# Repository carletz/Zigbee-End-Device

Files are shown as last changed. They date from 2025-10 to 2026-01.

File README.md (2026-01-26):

# Zigbee End Device V2 (Contact Sensor)

This project is a **Zigbee End Device** designed to operate as a **battery-powered contact sensor** (for doors, windows, or similar applications).  
It is based on the **Texas Instruments CC2530** Zigbee SoC and can be flashed with the **PTVO firmware** to provide full Zigbee functionality.

The aim of this project is to replicate the door/window contact and try to do it as small as possible. The first attempt was made with 0402 components, easy and beautiful to design but extremely hard in the real life to solder. This version is based on 0603 pieces which are "more easy" to prepare by hand.
I've do my best! 🤣

Okay, okay... I've discovered hot water...  these are sensors that can be easily purchased off the shelf without too many problems, I know. The purpose of my work was simply to try to understand how they work and, consequently, their potential, starting with the oldest and most established chip on the market. It's not a major innovation, but it certainly helps us understand the possibilities ahead.

📂 [--&gt; My OshwLab repository of the project](https://oshwlab.com/carletz.slug/zigbee-end-device-v21) 

---
## 🎥 Construction Video

Watch the video (https://youtu.be/N2DPDZoxfj0) 
---

## 🧩 Features

- Zigbee 1.2 compatible (using [PTVO firmware](https://ptvo.info/))
- Based on **CC2530F256** microcontroller  
- Powered by a **CR2032 coin cell**
- Integrated **reed switch** for contact detection  
- **LED indicator** for status or pairing feedback  
- **Reset button** for firmware or network reset  
- Compact design suitable for enclosure integration  

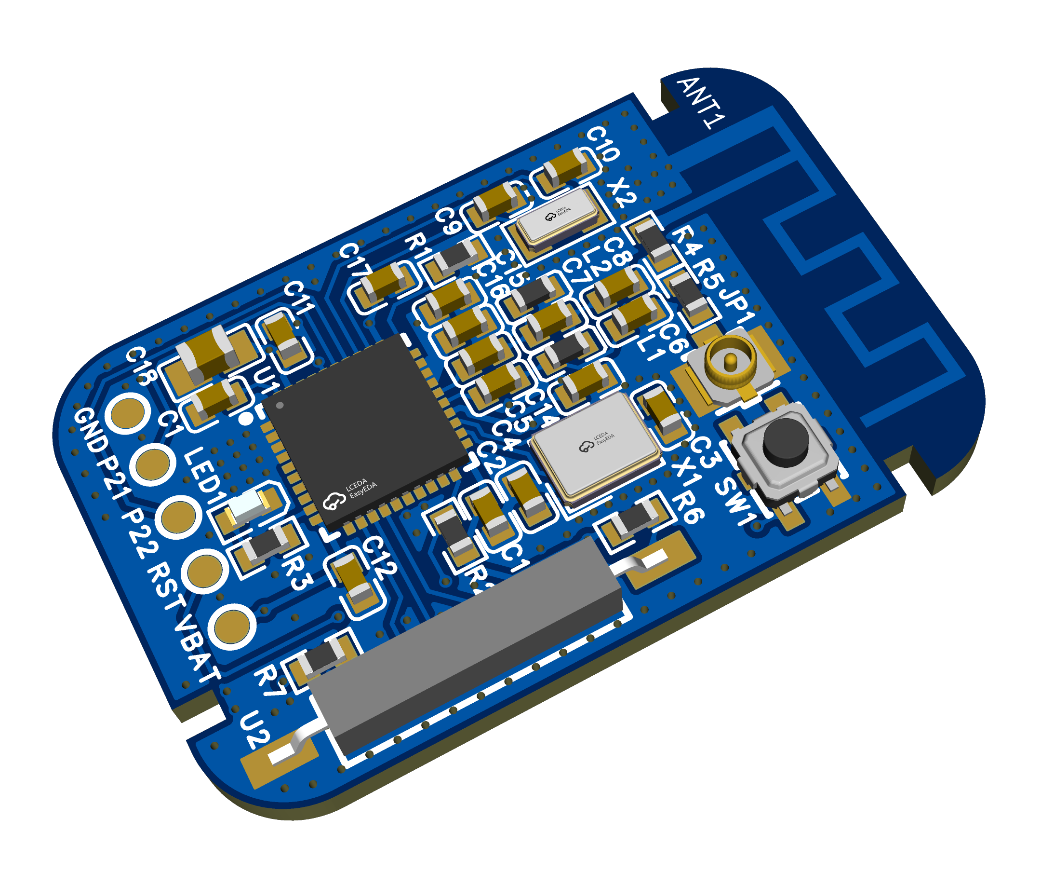
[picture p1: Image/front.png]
Render 1


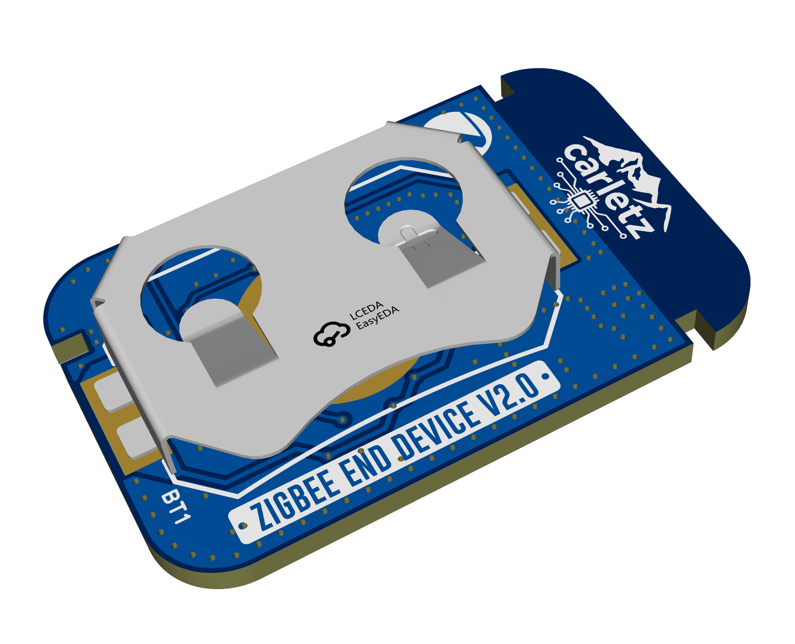
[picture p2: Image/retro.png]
Render 2


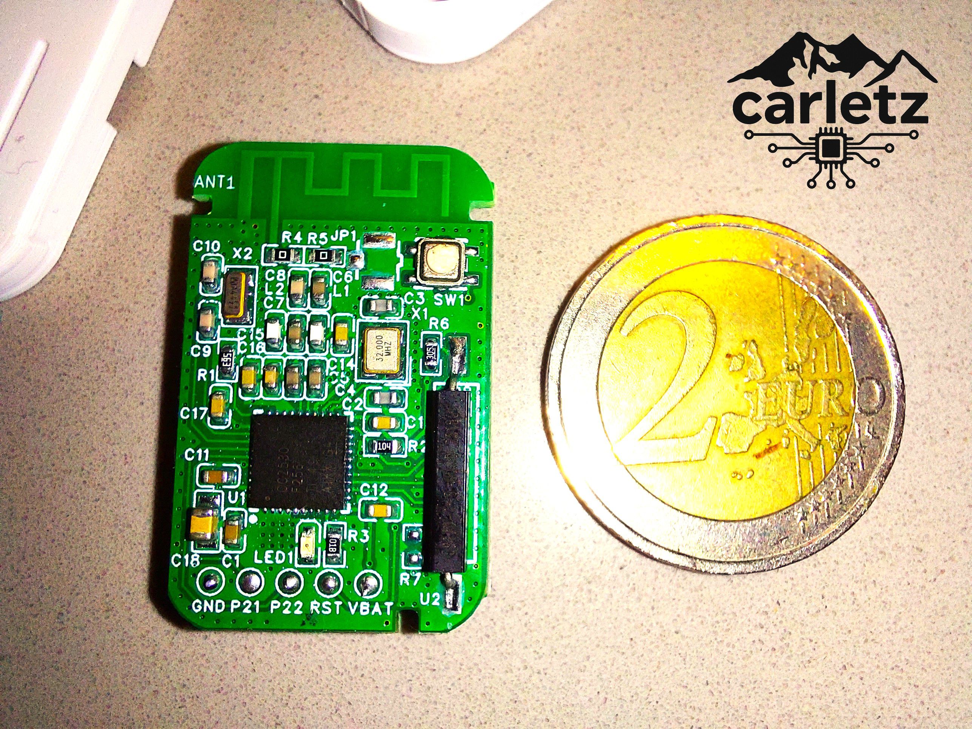
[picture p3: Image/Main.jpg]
Render 3

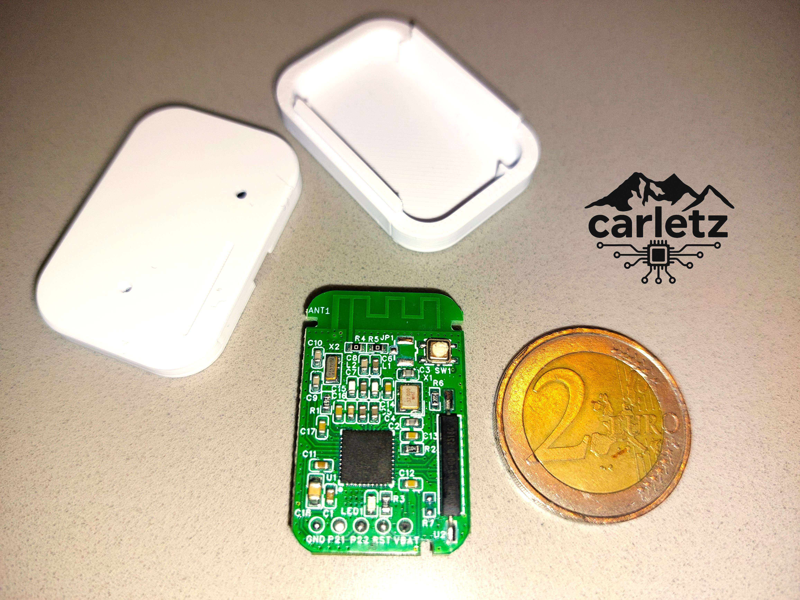
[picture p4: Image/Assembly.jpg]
Render 4

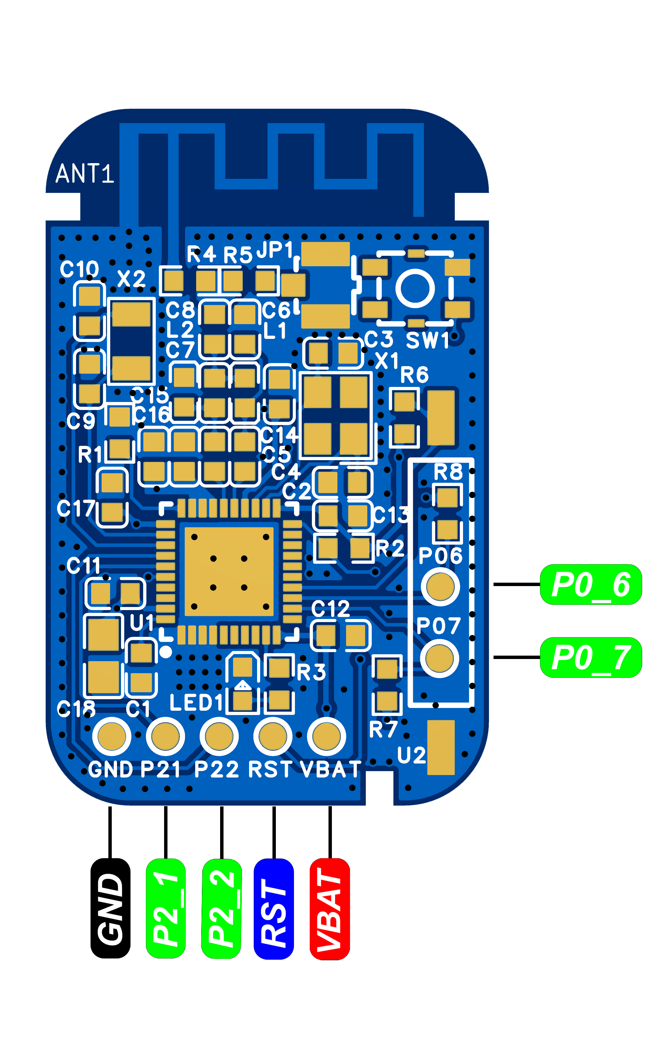
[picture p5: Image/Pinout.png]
Render 5


---
## ⚠️ Notes
- Pogo pins on the left are only for programming.
- I've added also the base for an external antenna but I didn't use it.
---

## 🛠️ Tools &amp; Compatibility

- Designed in **EasyEDA**
- Compatible with **Zigbee2MQTT**, **Home Assistant**, **OpenHAB**, and other automation platforms
- Zigbee module (CC2530) flashable via programmer and **TI Flash Programmer** 

## ⚙️ Firmware

The hardware is compatible with the **PTVO Zigbee firmware** generator:  
👉 [https://ptvo.info](https://ptvo.info)

You can configure the firmware as an **End Device (battery-powered)** and assign the reed contact input to the relative GPIO.

Once the configuration is ready, download the `.hex` file generated by the PTVO tool and flash it to the CC2530 chip.

---

## 🔋Battery

I wanted to try battery power for the first time on a simple project. With the configuration I used, the precautions taken to connect the sensor and power capacitors, and the firmware configuration, the sleep power consumption is approximately 3-4 µA, which guarantees significant battery life.

---

## 🔧 Flashing Instructions

To upload the firmware to the CC2530, follow these steps:

1. **Required tools:**
   - A **CC Debugger** or compatible programmer (I've used the cheaper SmartRF04EB)
   - The **SmartRF Flash Programmer** or **TI Flash Programmer** software
   - The `.hex` file generated by PTVO

2. **Connections:**

   | CC2530 Pin | CC Debugger Pin |
   |-------------|-----------------|
   | `P2_2` (Debug Data) | `DD` |
   | `P2_1` (Debug Clock) | `DC` |
   | `GND` | `GND` |
   | `VCC` | `VCC` (3.3 V) |
   | `RESET_N` | `RESET` |

Others test point applied are for eventually future implementations whit an optiona pull-up resistor.

3. **Flashing procedure:**
   - Connect the programmer board to the Zigbee End Device board.
   - Verify that the programmer board LED turns red (indicating correct connection).
   - Open **SmartRF Flash Programmer**.
   - Select the connected device (**CC2530**).
   - Choose your `.hex` file.
   - Click **Program** and wait for the operation to complete.

4. **After flashing:**
   - Disconnect the programmer.
   - Power the device from the CR2032 battery.
   - The LED should blink once at startup, and the device will join the Zigbee network when powered.

---

## 💡 Credits

This project is inspired by and based on designs shared by **[DIY&amp;Zi](https://oshwlab.com/novgorod73/works)** on [OSHWHub / OSHWLab](https://oshwlab.com).  
Special thanks to **PTVO** for providing a lot of informations for the tune of this board and flexible **Zigbee firmware generator**.

---

## 📬 Author

**carletz**  
Created: January 2026
This project is open hardware, released under the MIT License.

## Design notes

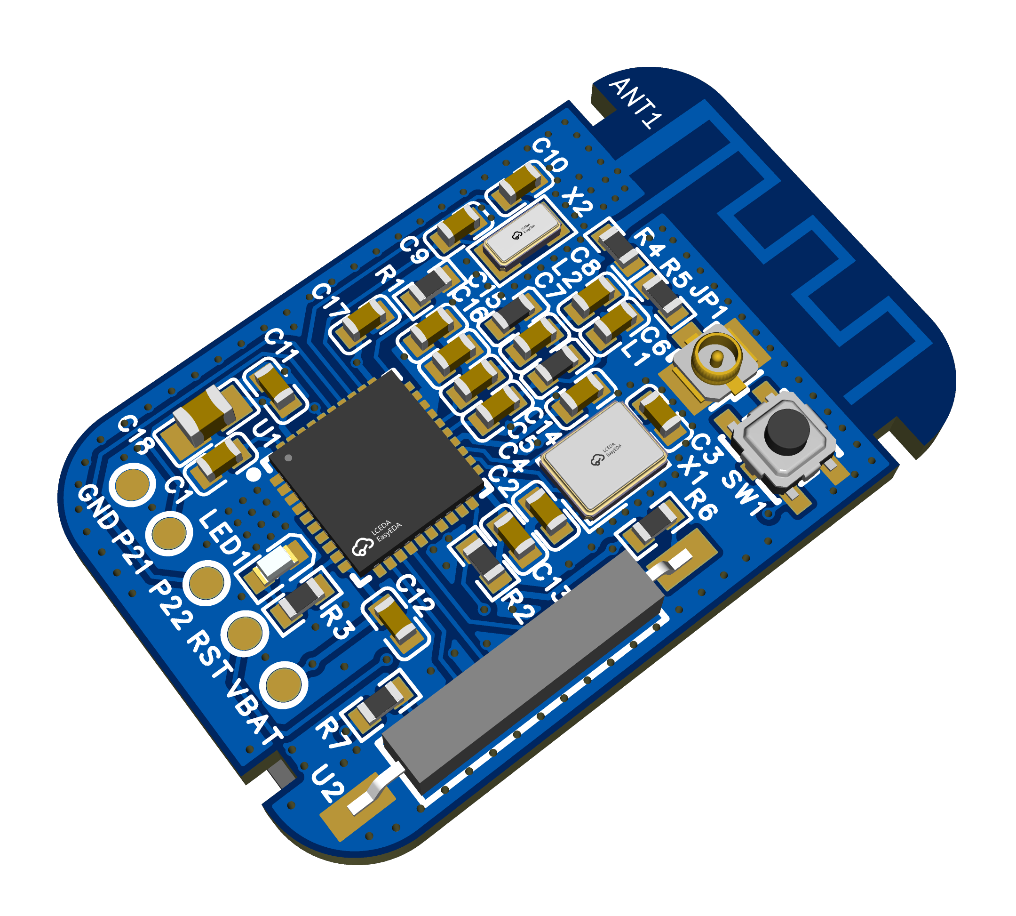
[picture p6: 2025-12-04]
Image/top.png

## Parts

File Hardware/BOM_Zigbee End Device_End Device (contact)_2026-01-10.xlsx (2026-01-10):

No. | Quantity | Comment | Designator | Footprint | Value | Manufacturer Part | Manufacturer | Supplier Part | Supplier | LCSC Stock | LCSC Price | Primary Category | Secondary Category | Pin Count | JLCPCB Stock | JLCPCB Price | 3D Model Title | Device | Name | Unique ID | Convert to PCB | Add into BOM | Symbol
1 | 1 | MY-2032-12 | BT1 | BAT-SMD_MY-2032-12 |  | MY-2032-12 | MYOUNG(美阳) | C964833 | LCSC |  |  | Connectors | Button And Strip Battery Connector | 2 | 18862 | 0.0198 | BAT-SMD_MY-2032-12 | MY-2032-12 | MY-2032-12 | gge17 | yes | yes | MY-2032-12
2 | 2 | 1uF | C1,C11 | C0603 | 1uF | CL10A105KA8NNNC | SAMSUNG(三星) | C5673 | LCSC |  |  | Capacitors | Multilayer Ceramic Capacitors MLCC - SMD/SMT | 2 | 1186170 | 0.0007 | C0603_L1.6-W0.8-H0.8 | CL10A105KA8NNNC | 1uF | gge37,gge38 | yes | yes | CL10A105KA8NNNC
3 | 2 | 27pF | C2,C3 | C0603 | 27pF | CGA0603C0G270J500JT | HRE(芯声) | C42371680 | LCSC |  |  | Capacitors | Multilayer Ceramic Capacitors MLCC - SMD/SMT | 2 | 0 |  | C0603_L1.6-W0.8-H0.8 | CGA0603C0G270J500JT | 27pF | gge50,gge51 | yes | yes | CGA0603C0G270J500JT
4 | 2 | 18pF | C4,C5 | C0603 | 18pF | FCC0603N180J500CT | FOJAN(富捷) | C5137620 | LCSC |  |  | Capacitors | Multilayer Ceramic Capacitors MLCC - SMD/SMT | 2 | 412623 | 0.0004 | C0603_L1.6-W0.8-H0.8 | FCC0603N180J500CT | 18pF | gge56,gge57 | yes | yes | FCC0603N180J500CT
5 | 2 | 1pF | C6,C7 | C0603 | 1pF | FCC0603N1R0C500CT | FOJAN(富捷) | C5137611 | LCSC |  |  | Capacitors | Multilayer Ceramic Capacitors MLCC - SMD/SMT | 2 | 154670 | 0.0004 | C0603_L1.6-W0.8-H0.8 | FCC0603N1R0C500CT | 1pF | gge52,gge53 | yes | yes | FCC0603N1R0C500CT
6 | 1 | 2.2pF | C8 | C0603 | 2.2pF | 0603CG2R2C500NT | FH(风华) | C1651 | LCSC |  |  | Capacitors | Multilayer Ceramic Capacitors MLCC - SMD/SMT | 2 | 137377 | 0.0005 | C0603_L1.6-W0.8-H0.8 | 0603CG2R2C500NT | 2.2pF | gge58 | yes | yes | 0603CG2R2C500NT
7 | 2 | 15pF | C9,C10 | C0603 | 15pF | 0603CG150J500NT | FH(风华) | C91703 | LCSC |  |  | Capacitors | Multilayer Ceramic Capacitors MLCC - SMD/SMT | 2 | 114833 | 0.0005 | C0603_L1.6-W0.8-H0.8 | 0603CG150J500NT | 15pF | gge39,gge40 | yes | yes | 0603CG150J500NT
8 | 5 | 100nF | C12,C13,C14,C15,C17 | C0603 | 100nF | CL10B104KO8NNNC | SAMSUNG(三星) | C66501 | LCSC |  |  | Capacitors | Multilayer Ceramic Capacitors MLCC - SMD/SMT | 2 | 568617 | 0.0005 | C0603_L1.6-W0.8-H0.8 | CL10B104KO8NNNC | 100nF | gge41,gge42,gge43,gge44,gge45 | yes | yes | CL10B104KO8NNNC
9 | 1 | 220pF | C16 | C0603 | 220pF | CC0603KRX7R9BB221 | YAGEO(国巨) | C107081 | LCSC |  |  | Capacitors | Multilayer Ceramic Capacitors MLCC - SMD/SMT | 2 | 580953 | 0.0005 | C0603_L1.6-W0.8-H0.8 | CC0603KRX7R9BB221 | 220pF | gge59 | yes | yes | CC0603KRX7R9BB221
10 | 1 | 100uF | C18 | C0805 | 100uF | GRM21BR60J107ME15L | muRata(村田) | C141660 | LCSC |  |  | Capacitors | Multilayer Ceramic Capacitors MLCC - SMD/SMT | 2 | 114779 | 0.0359 | C0805_L2.0-W1.3-H1.3 | GRM21BR60J107ME15L | 100uF | gge36 | yes | yes | GRM21BR60J107ME15L
11 | 7 | 3V3 | GND,P06,P07,P21,P22,RST,VBAT | TESTPOINT-TH_BD3.2_1 |  | 3V3 |  | C9900007422 | LCSC |  |  |  |  | 1 | 0 | 0.0002 |  | TPoint2 | 3V3 | gge122_2,gge122_3,gge122_4,gge122_5,gge122_6,gge122_7,gge122_8 | yes | yes | TPoint2
12 | 1 | 6GHz | JP1 | RF-SMD_FRF05002-JSS103M | 6GHz | U.FL-R-SMT-1(80) | HRS(广濑) | C88374 | LCSC |  |  | Connectors | Coaxial Connectors (RF) | 3 | 69527 | 0.0179 | RF-SMD_FRF05002-JSS103M | U.FL-R-SMT-1(80)_C88374 | 6GHz | gge34 | yes | yes | U.FL-R-SMT-1(80)
13 | 2 | 2nH | L1,L2 | L0603 | 2nH | VHF160808H2N0ST | FH(风华) | C395081 | LCSC |  |  | Inductors, Coils, Chokes | Inductors (SMD) | 2 | 13488 | 0.0012 | L0603_L1.6-W0.8-H0.5_BEAD | VHF160808H2N0ST | 2nH | gge54,gge55 | yes | yes | VHF160808H2N0ST
14 | 1 | MHT192CRCT | LED1 | LED0603-RD |  | MHT192CRCT | MEIHUA(美华) | C389517 | LCSC |  |  | Optoelectronics | LED Indication - Discrete | 2 | 155827 | 0.0033 | LED0603-RD | MHT192CRCT | MHT192CRCT | gge48 | yes | yes | MHT192CRCT
15 | 1 | 56kΩ | R1 | R0603 | 56kΩ | FRC0603F5602TS | FOJAN(富捷) | C2907053 | LCSC |  |  | Resistors | Chip Resistor - Surface Mount | 2 | 16 | 0.0002 | R0603 | FRC0603F5602TS | 56kΩ | gge62 | yes | yes | FRC0603F5602TS
16 | 1 | 100kΩ | R2 | R0603 | 100kΩ | RS-03K104JT | FH(风华) | C73806 | LCSC |  |  | Resistors | Chip Resistor - Surface Mount | 2 | 17835 | 0.0002 | R0603 | RS-03K104JT | 100kΩ | gge49 | yes | yes | RS-03K104JT
17 | 1 | 1kΩ | R3 | R0603 | 1kΩ | RS-03K1001FT | FH(风华) | C115325 | LCSC |  |  | Resistors | Chip Resistor - Surface Mount | 2 | 800933 | 0.0002 | R0603 | RS-03K1001FT | 1kΩ | gge46 | yes | yes | RS-03K1001FT
18 | 2 | 0Ω | R4,R5 | R0603 | 0Ω | RC0603FR-070RL | YAGEO(国巨) | C100044 | LCSC |  |  | Resistors | Chip Resistor - Surface Mount | 2 | 5592076 | 0.0002 | R0603 | RC0603FR-070RL | 0Ω | gge60,gge61 | yes | yes | RC0603FR-070RL
19 | 3 | 3MΩ | R6,R7,R8 | R0603 | 3MΩ | RS-03L3004FT | FH(风华) | C212253 | LCSC |  |  | Resistors | Chip Resistor - Surface Mount | 2 | 6502 | 0.0003 | R0603 | RS-03L3004FT_C212253 | 3MΩ | gge47,gge47_1,gge47_2 | yes | yes | RS-03L3004FT_C212253
20 | 1 | TSA007A1518B03 | SW1 | SW-SMD_4P-L3.4-W3.4-P2.00-LS4.0_YTSA007AXXXX |  | TSA007A1518B03 | BZCN(博众电气) | C2888419 | LCSC |  |  | Switches | Tactile Switches | 5 | 776 | 0.004 | SW-SMD_4P-L3.4-W3.4-P2.00-LS4.0_YTSA007AXXXX | TSA007A1518B03 | TSA007A1518B03 | gge27 | yes | yes | TSA007A1518B03
21 | 1 | CC2530F256RHAR | U1 | QFN-40_L6.0-W6.0-P0.50-TL-EP4.1 |  | CC2530F256RHAR | TI(德州仪器) | C9120 | LCSC |  |  | RF and Wireless | RF Transceiver ICs | 41 | 6122 | 0.3235 | QFN-40_L6.0-W6.0-P0.50-TL-EP4.1 | CC2530F256RHAR | CC2530F256RHAR | gge1 | yes | yes | CC2530F256RHAR_C9120
22 | 1 | 59170-1-S-00-D | U2 | SENSOR-SMD_59170-1-S-00-D |  | 59170-1-S-00-D | Littelfuse(美国力特) | C315909 | LCSC |  |  |  |  | 2 | 30305 | 0.0833 | SENSOR-SMD_L11.4-W2.3-H2.3-59170-1-S-00-D | 59170-1-S-00-D | 59170-1-S-00-D | gge26 | yes | yes | 59170-1-S-00-D
23 | 1 | 32MHz | X1 | CRYSTAL-SMD_4P-L3.2-W2.5-BL | 32MHz | TXM32M0004322DBCDO00T | YJX(雅晶鑫) | C362339 | LCSC |  |  | Crystals, Oscillators, Resonators | Crystals | 4 | 6908 | 0.0093 | CRYSTAL-SMD_4P-L3.2-W2.5-BL | TXM32M0004322DBCDO00T | 32MHz | gge6 | yes | yes | SMD-3225_4P 32.000MHZ 10PF
24 | 1 | 32.768KHZ | X2 | OSC-SMD_L3.2-W1.5 | 32.768KHZ | NX3215SA-32.768KHZ-EXS00A-MU00466 | NDK |  | LCSC |  |  | Crystals, Oscillators, Resonators | Crystals | 2 |  |  | OSC-SMD_L3.2-W1.5-H0.8 | NX3215SA-32.768KHZ-EXS00A-MU00466 | 32.768KHZ | gge16 | yes | yes | NX3215SA 32.768KHZ 12.5PF 20PPM

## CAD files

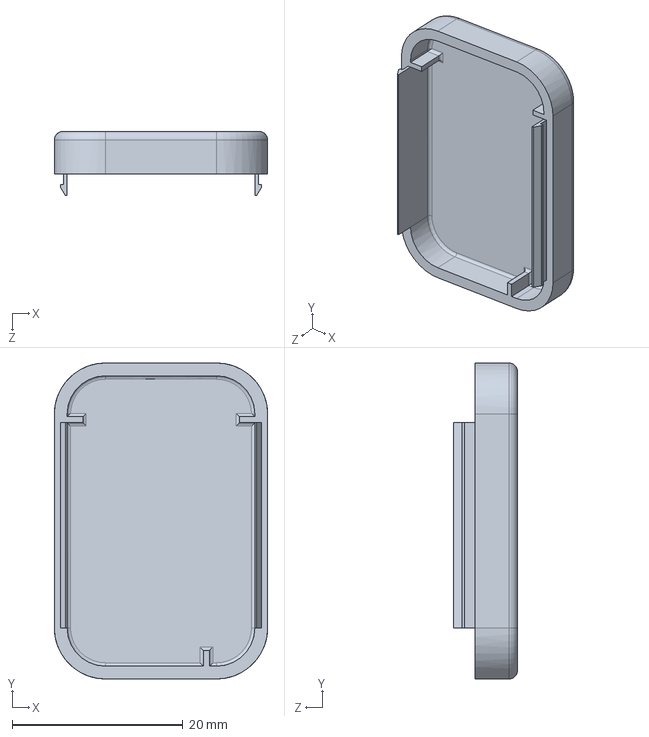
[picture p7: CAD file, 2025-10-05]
3D shell/COVER BOTTOM.SLDPRT
25.0 x 37.0 x 7.50 mm

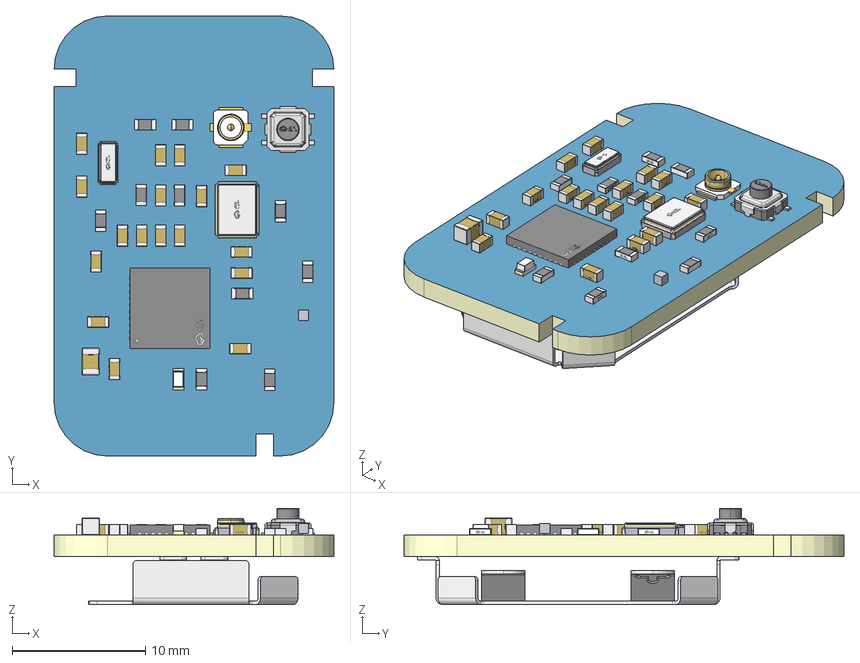
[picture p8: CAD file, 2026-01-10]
Hardware/3D_End Device_2026-01-10.step
21.0 x 33.0 x 7.20 mm
Board~m7uJ
TopCopper~m7uJ
BottomCopper~m7uJ
TopFpcStiffener~m7uJ
BottomFpcStiffener~m7uJ
SENSOR-SMD_59170-1-S-00-D~SENSOR-SMD_ L11.4-W2.3-H2.3-59170-1-S-00-D~m7uJ
QFN-40_L6.0-W6.0-P0.50-TL-EP4.1~TQFN-40_L6.0-W6.0-P0.50-TL-EP4.1~m7uJ
BAT-SMD_MY-2032-12~BAT-SMD_MY-2032-12~m7uJ
CRYSTAL-SMD_4P-L3.2-W2.5-BL~X1~CRYSTAL-SMD_4P-L3.2-W2.5-BL~CRYSTAL-SMD_ 4P-L3.2-W2.5-BL~Ifhw~m7uJ
OSC-SMD_L3.2-W1.5~OSC-SMD_L3.2-W1.5-H0.8~m7uJ
C0805~C0805_L2.0-W1.3-H1.3~m7uJ
L0603~L0603_L1.6-W0.8-H0.5_BEAD~m7uJ x 2
SW-SMD_4P-L3.4-W3.4-P2.00-LS4.0_YTSA007AXXXX~SW-SMD_ 4P-L3.4-W3.4-P2.00-LS4.0_YTSA007AXXXX~m7uJ
LED0603-RD~LED0603-RD_IR19-21C-TR8~m7uJ
R0603~R0603_L1.6-W0.8-H0.5~m7uJ x 8
C0603~C0603_L1.6-W0.8-H0.8~m7uJ x 17
RF-SMD_FRF05002-JSS103M~RF-SMD_FRF05002-JSS103M~m7uJ

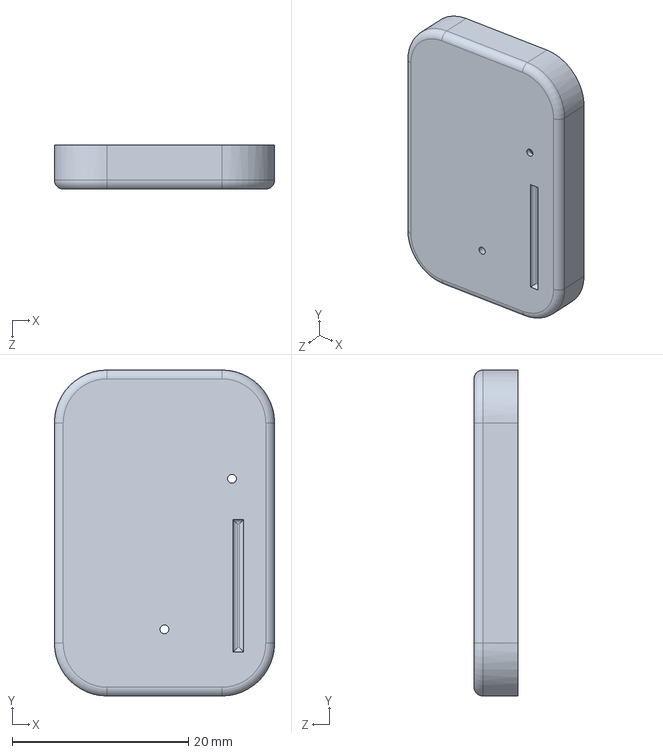
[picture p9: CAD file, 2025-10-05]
3D shell/COVER UPPER.SLDPRT
25.0 x 37.0 x 5.00 mm

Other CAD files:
3D shell/COVER BOTTOM.STL
3D shell/COVER UPPER.STL

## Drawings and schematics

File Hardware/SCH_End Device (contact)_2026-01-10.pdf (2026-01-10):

# Zigbee End Device V2 (Contact Sensor)

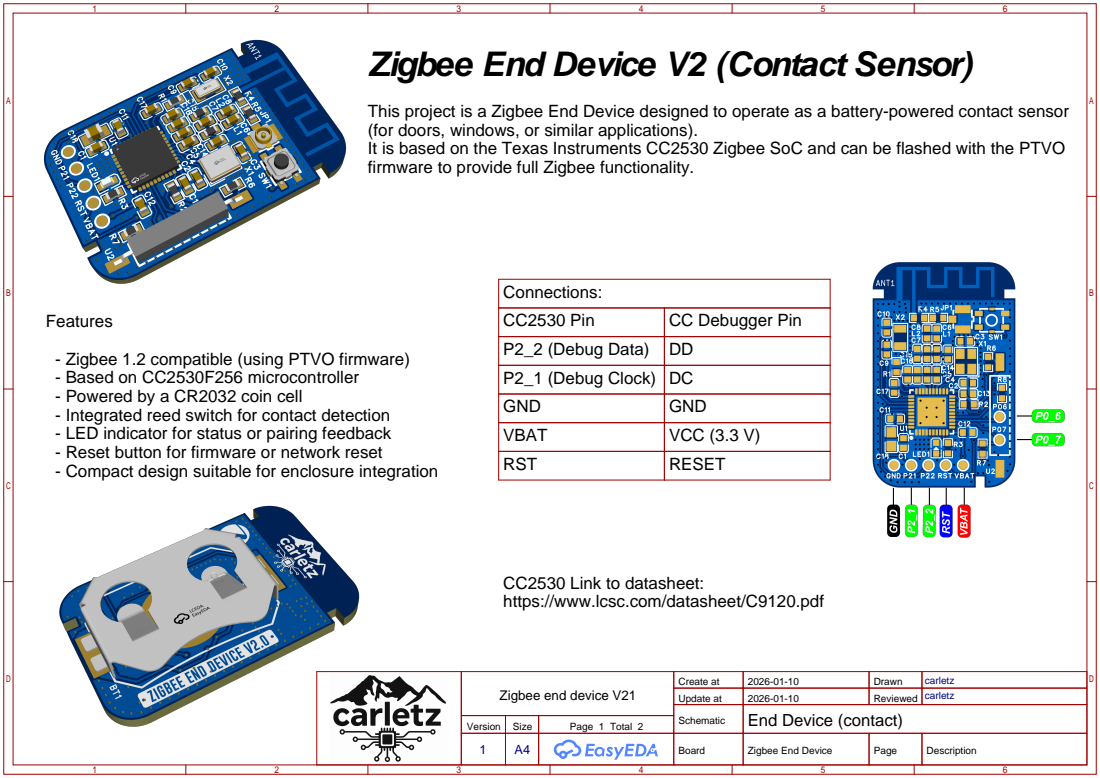
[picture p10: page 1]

This project is a Zigbee End Device designed to operate as a battery-powered contact sensor
(for doors, windows, or similar applications).
It is based on the Texas Instruments CC2530 Zigbee SoC and can be flashed with the PTVO
firmware to provide full Zigbee functionality.

Features
- Zigbee 1.2 compatible (using PTVO firmware)
- Based on CC2530F256 microcontroller
- Powered by a CR2032 coin cell
- Integrated reed switch for contact detection
- LED indicator for status or pairing feedback
- Reset button for firmware or network reset
- Compact design suitable for enclosure integration

CC2530 Pin | CC Debugger Pin
P2_2 (Debug Data) | DD
P2_1 (Debug Clock) | DC
GND | GND
VBAT | VCC (3.3 V)
RST | RESET

CC2530 Link to datasheet:
https://www.lcsc.com/datasheet/C9120.pdf

Zigbee end device V21 | Create at | 2026-01-10 | Drawn | carletz

Update at | 2026-01-10 | Reviewed | carletz

Schematic
1 | A4 | | Board | Zigbee End Device | Page | Description

Size | Page 1 Total 2 | End Device (contact) Version

## Battery Power

## Antenna

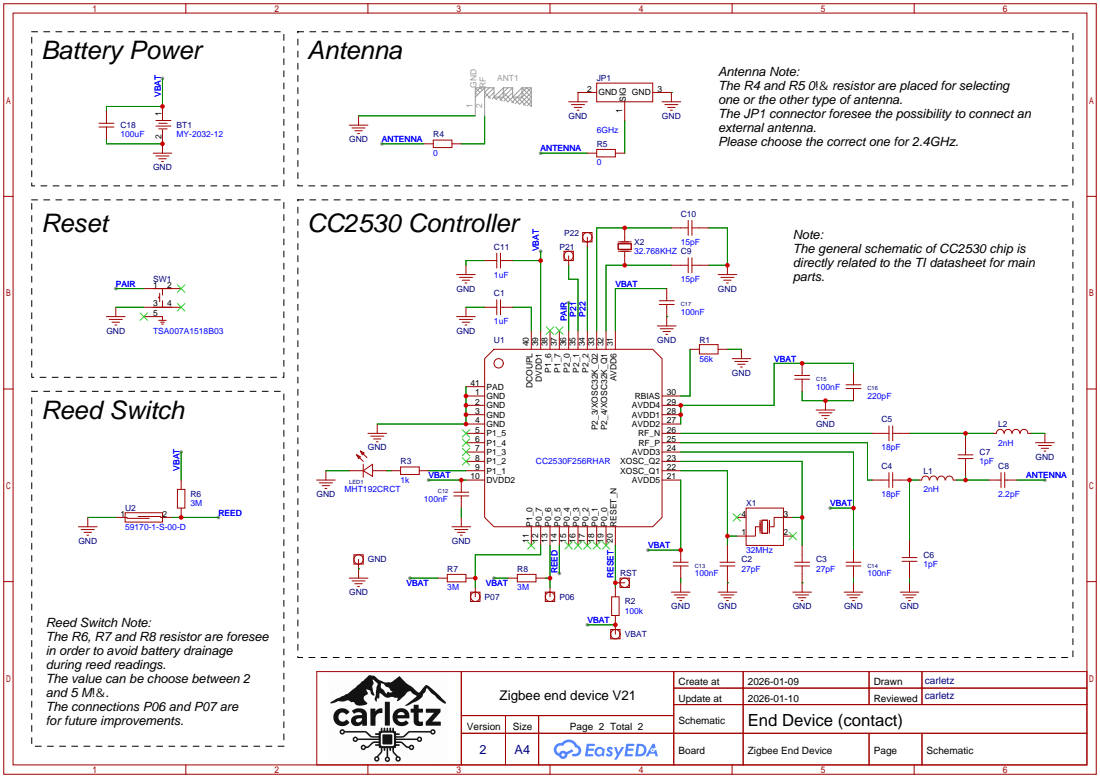
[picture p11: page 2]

Antenna Note:
The R4 and R5 0!& resistor are placed for selecting
one or the other type of antenna.
The JP1 connector foresee the possibility to connect an
external antenna.
Please choose the correct one for 2.4GHz.

Note:
The general schematic of CC2530 chip is
directly related to the TI datasheet for main
parts.

Reed Switch Note:
The R6, R7 and R8 resistor are foresee
in order to avoid battery drainage
during reed readings.
The value can be choose between 2
and 5 M!&.
The connections P06 and P07 are
for future improvements.

Zigbee end device V21 | Create at | 2026-01-09 | Drawn | carletz

Update at | 2026-01-10 | Reviewed | carletz

Schematic
2 | A4 | | Board | Zigbee End Device | Page | Schematic

Size | Page 2 Total 2 | End Device (contact) Version

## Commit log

2025-12-04 Revise README for Zigbee End Device V2
    Updated project details and features for Zigbee End Device V2.
2026-01-09 Update README with battery info and author date
    Added battery power section and updated author date.
2026-01-09 Revise README for Zigbee End Device V2
    Updated project details, features, flashing instructions, and added images.
